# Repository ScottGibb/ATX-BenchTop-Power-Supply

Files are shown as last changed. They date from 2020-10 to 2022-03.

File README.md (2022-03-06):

# ATX-BenchTop-Power-Supply
Circuit diagram and Layout files for an ATX Bench Top open-source Power Supply

The circuit was created in Eagle using both through-hole and surface-mount components. The power supply board is developed such that it can use an old PC ATX power supply.
CAD design was done using Fusion 360 and will be available on thingiverse:

Thingiverse Link:
TBC

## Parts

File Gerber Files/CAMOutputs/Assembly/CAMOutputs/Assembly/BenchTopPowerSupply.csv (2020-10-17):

C7  3.29  5.94 270 0.1uF C1206
C9 28.94 84.82 180 0.1uF C1206
C10 37.96  5.52 270 0.1uF C1206
C11 118.75 62.00 180 0.1uF C1206
C12 133.73 77.01  90 01.uF C1206
C20 120.04 57.40 180 100nF C1206
C21 69.27 39.07   0 100nF C1206
C22 69.27 41.26   0 1uF C1206
C24 19.28 43.03 180 100nF C1206
C25 16.85 45.66 180 1uF C1206
C28 86.91 44.59 180 100nF C1206
C29 87.07 42.27 180 1uF C1206
C30 34.63 42.66   0 1uF C1206
C31 34.66 40.42   0 100nF C1206
C32 51.54 46.62 180 100nF C1206
C33 51.57 43.88 180 1uF C1206
C34 23.19 62.81  90 100nF C1206
C36 146.20 84.07   0 100uF C1206
C38 135.04 64.58   0 100uF C1206
R2 52.13  7.61  90 470 R1206
R3 20.00  6.76  90 470 R1206
R5  4.53 46.19  90 300K R1206
R6 151.13 13.97   0 220 R1206
R7 135.89 13.97   0 220 R1206
R8 119.38 13.97   0 470 R1206
R9 51.08 33.63   0 10k R1206
R10 64.77 74.93  90 220 R1206
R11 46.56 90.30 180 220 R1206
R12 17.67 33.15   0 10k R1206
R13 87.17 32.41   0 10k R1206
R14  6.27 42.48   0 100K R1206
R15  7.67 10.74 270 0.1R RESC6335X60N
R18 130.10 83.19 180 0.005 RESC6335X60N
R19 29.21 76.20   0 0.005 RESC6335X60N
R20 114.30 68.58 180 0.005 RESC6335X60N
R21 37.05 33.03  90 300K R1206
R22 37.07 26.10  90 100K R1206
R26 109.58 62.92 180 30K R1206
R27 125.32 78.16   0 30K R1206
R28 34.06 82.91   0 30K R1206
R30  1.92 15.05 270 10k R1206
R35 29.92 63.28  90 10k R1206
R36 29.91 58.05  90 10k R1206
U1  3.63 11.00 270  SOT95P240X110-5N
U4 29.26 81.28   0  SOT95P240X110-5N
U5 130.05 77.47 180  SOT95P240X110-5N
U6 114.05 64.26 180  SOT95P240X110-5N

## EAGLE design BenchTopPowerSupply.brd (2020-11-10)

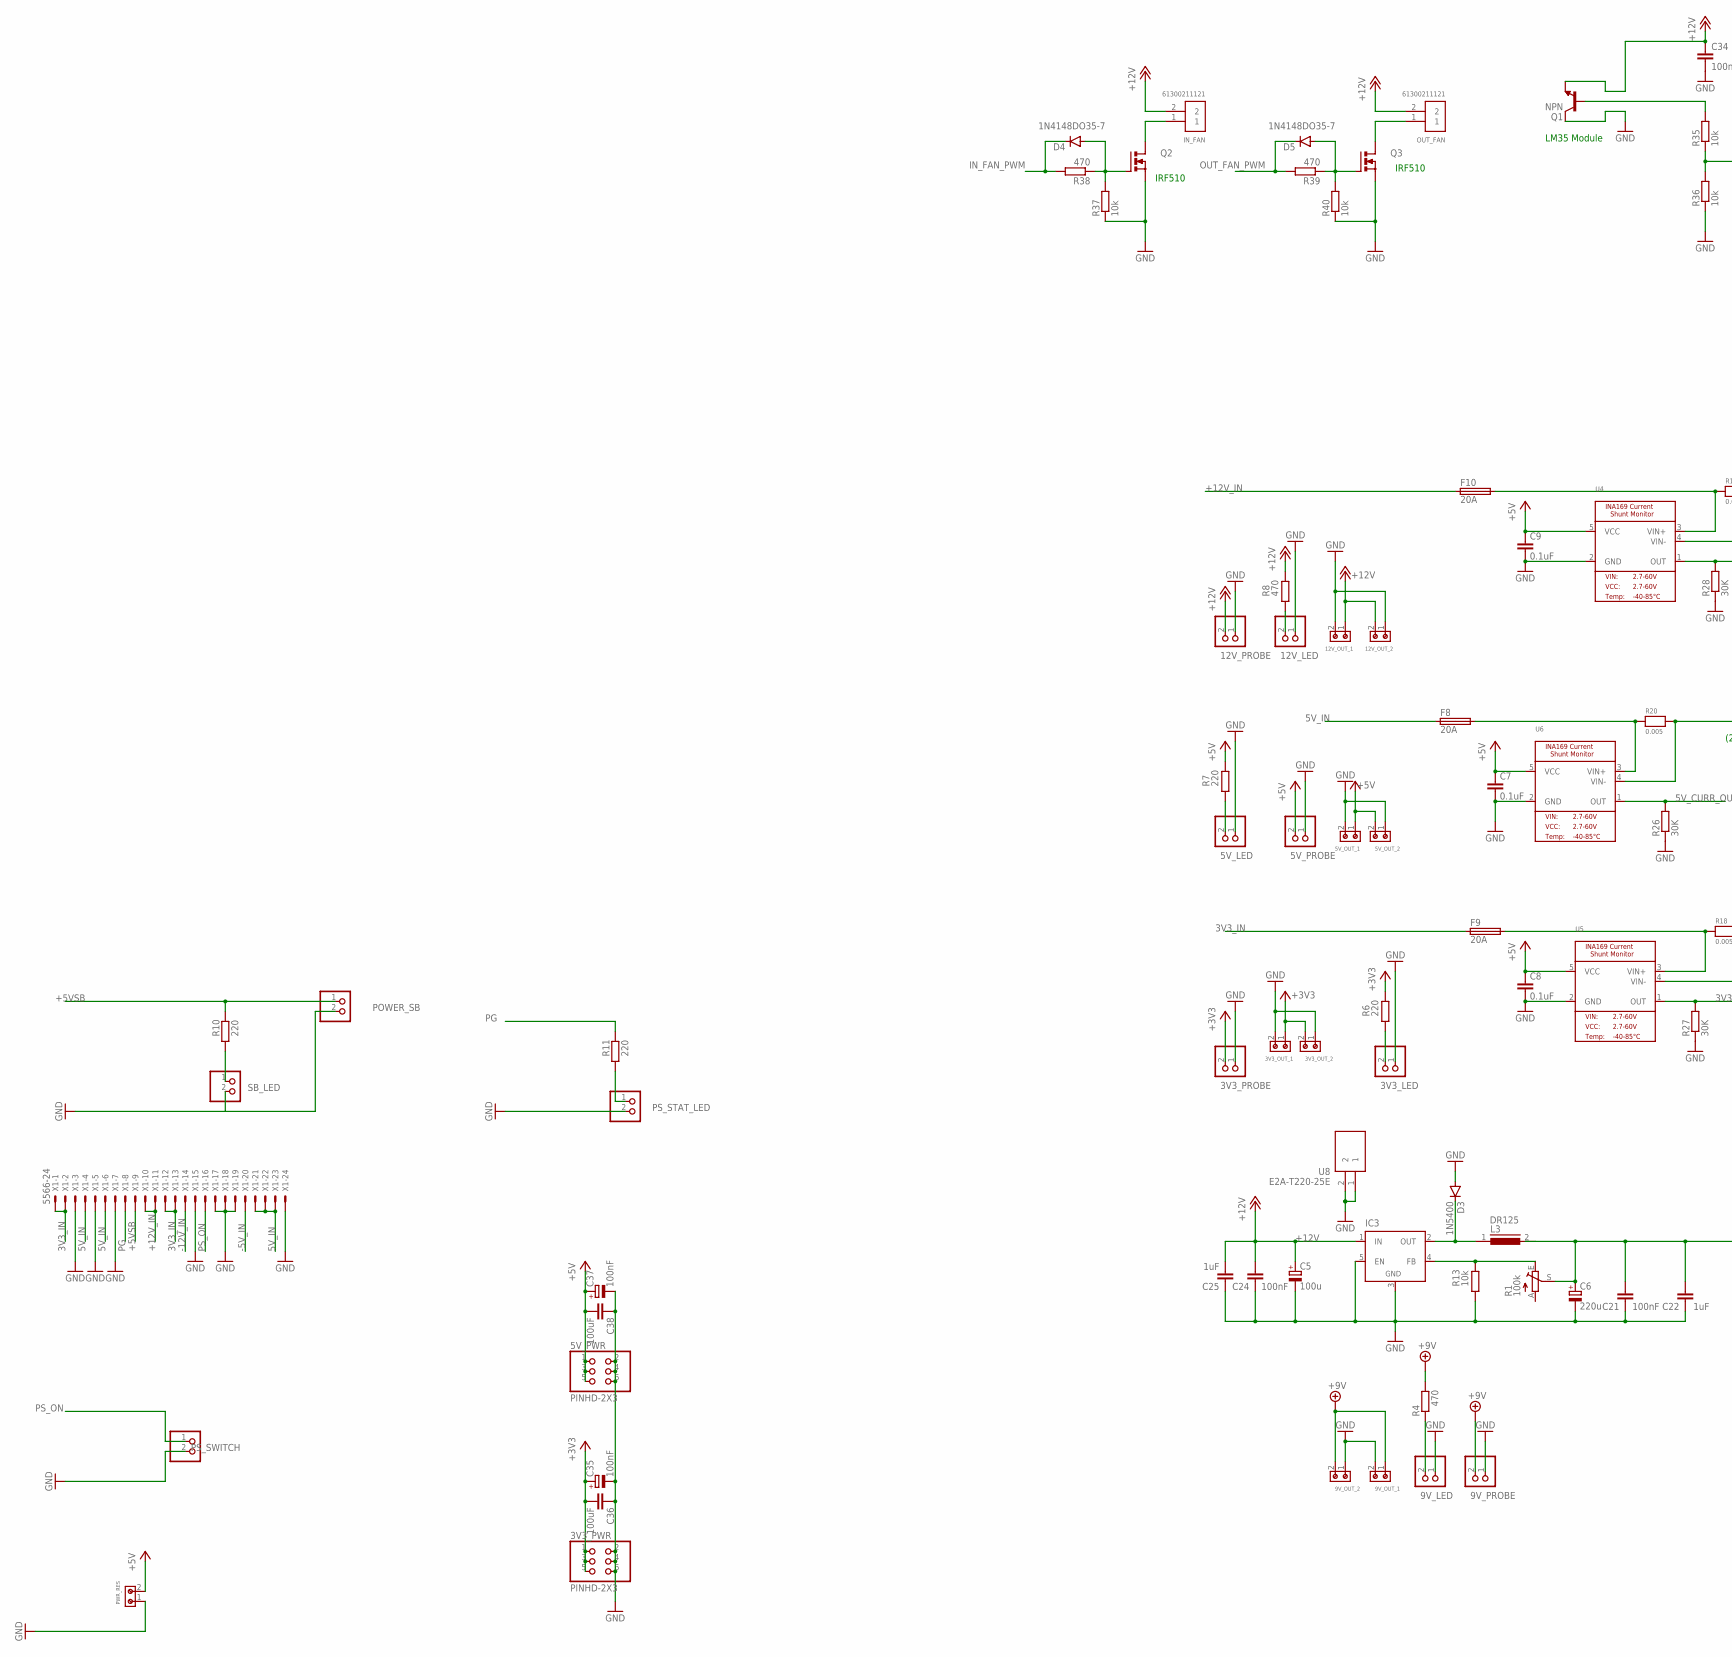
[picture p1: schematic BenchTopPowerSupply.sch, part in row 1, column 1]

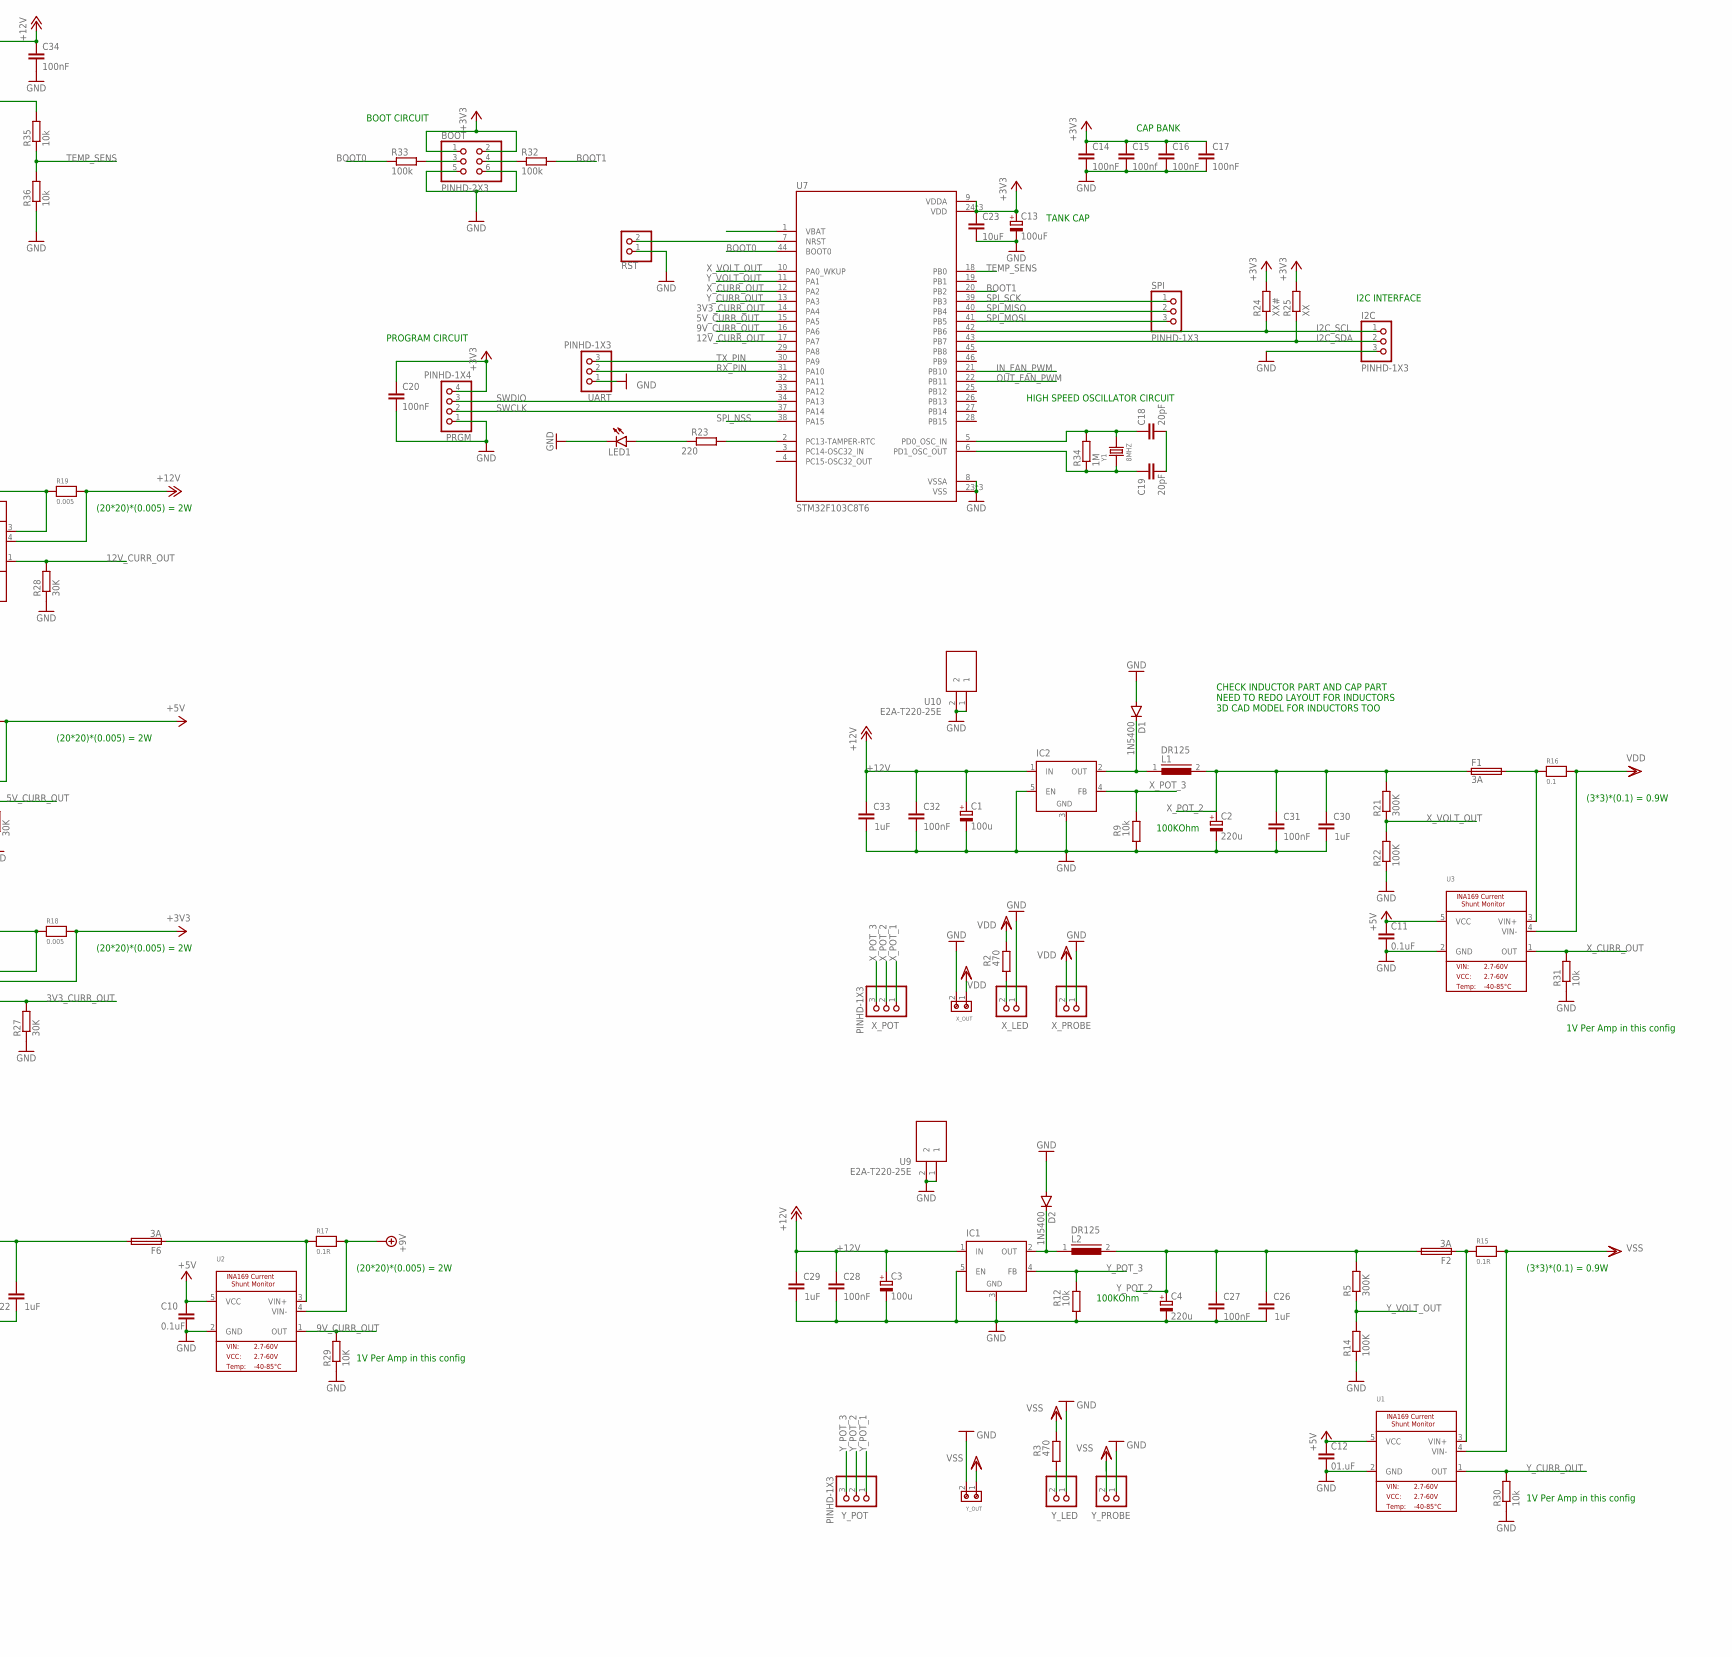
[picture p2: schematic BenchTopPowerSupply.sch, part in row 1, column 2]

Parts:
3V3_LED, 3V3_PROBE, 5V_LED, 5V_PROBE, 9V_LED, 9V_PROBE, 12V_LED, 12V_PROBE: PINHD-1X2; 1X02
3V3_OUT_1, 3V3_OUT_2, 5V_OUT_1, 5V_OUT_2, 9V_OUT_1, 9V_OUT_2, 12V_OUT_1, 12V_OUT_2: 691216510002S
3V3_PWR, 5V_PWR: PINHD-2X3; 2X03
BOOT: PINHD-2X3; 2X03
C1, C3, C5: 100u; E5-10,5
C2, C4, C6: 220u; E5-10,5
C7, C8, C9, C10, C11: 0.1uF; C1206
C12: 01.uF; C1206
C13: 100uF; E5-5
C14, C16, C17, C20, C21, C24, C27, C28, C31, C32, C34: 100nF; C1206
C15: 100nf; C1206
C18, C19: 20pF; C1206
C22, C25, C26, C29, C30, C33: 1uF; C1206
C23: 10uF; C1206
C35, C37: 100nF; E5-5
C36, C38: 100uF; C1206
D1, D2, D3: 1N5400; DO201-15
D4, D5: 1N4148DO35-7; DO35-7
F1, F2, F6: 3A; SHK20L
F8, F9, F10: 20A; SHK20L
I2C: PINHD-1X3; 1X03
IC1, IC2, IC3: LM2596TV; TO220-51
IN_FAN: 61300211121
L1, L2, L3: DR125
LED1: LED5MM
OUT_FAN: 61300211121
POWER_SB: PINHD-1X2; 1X02
PRGM: PINHD-1X4; 1X04
PS_STAT_LED: PINHD-1X2; 1X02
PS_SWITCH: PINHD-1X2; 1X02
PWR_RES: 691216510002S
Q1: NPN; TO92
Q2, Q3: IRF510; TO220BV
R1: 100k; S64W
R2, R3, R4, R8, R38, R39: 470; R1206
R5, R21: 300K; R1206
R6, R7, R10, R11, R23: 220; R1206
R9, R12, R13, R30, R31, R35, R36, R37, R40: 10k; R1206
R14, R22: 100K; R1206
R15, R17: 0.1R; RESC6335X60N
R16: 0.1; RESC6335X60N
R18, R19, R20: 0.005; RESC6335X60N
R24: XX#; R1206
R25: XX; R1206
R26, R27, R28: 30K; R1206
R29: 10K; R1206
R32, R33: 100k; R1206
R34: 1M; R1206
RST: PINHD-1X2; 1X02
SB_LED: PINHD-1X2; 1X02
SPI: PINHD-1X3; 1X03
U1, U2, U3, U4, U5, U6: MICROBUILDER_INA1693D_PACKAGE; SOT95P240X110-5N
U7: STM32F103C8T6; QFP50P900X900X160-48N
U8, U9, U10: E2A-T220-25E; E2AT22025E
UART: PINHD-1X3; 1X03
X1: 5566-24
X_LED: PINHD-1X2; 1X02
X_OUT: 691216510002S
X_POT: PINHD-1X3; 1X03
X_PROBE: PINHD-1X2; 1X02
Y1: 8MHZ; HC49US
Y_LED: PINHD-1X2; 1X02
Y_OUT: 691216510002S
Y_POT: PINHD-1X3; 1X03
Y_PROBE: PINHD-1X2; 1X02

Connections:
2B: F2.1A, R15.1, U1.3 (VIN+)
3V3_CURR_OUT: R27.2, U5.1 (OUT), U7.14 (PA4)
3V3_IN: F9.1A, X1.1, X1.2, X1.12, X1.13
5V_CURR_OUT: R26.2, U6.1 (OUT), U7.15 (PA5)
5V_IN: F8.1A, X1.4, X1.6, X1.21, X1.22, X1.23
9V_CURR_OUT: R29.2, U2.1 (OUT), U7.16 (PA6)
12V_CURR_OUT: R28.2, U4.1 (OUT), U7.17 (PA7)
+3V3: 3V3_OUT_1.1, 3V3_OUT_2.2, 3V3_PROBE.2, 3V3_PWR.1, 3V3_PWR.3, 3V3_PWR.5, BOOT.1, BOOT.2, C13.+, C14.1, C15.1, C16.1, C17.1, C20.1, C23.1, C35.+, C36.2, PRGM.4, R6.2, R18.2, R24.2, R25.2, U5.4 (VIN-), U7.9 (VDDA), U7.24 (VDD), U7.36 (VDD), U7.48 (VDD)
+5V: 5V_OUT_1.1, 5V_OUT_2.2, 5V_PROBE.2, 5V_PWR.1, 5V_PWR.3, 5V_PWR.5, C7.1, C8.1, C9.1, C10.1, C11.1, C12.1, C37.+, C38.2, PWR_RES.2, R7.2, R20.2, U1.5 (VCC), U2.5 (VCC), U3.5 (VCC), U4.5 (VCC), U5.5 (VCC), U6.4 (VIN-), U6.5 (VCC)
+5VSB: POWER_SB.1, R10.2, X1.9
+9V: 9V_OUT_1.1, 9V_OUT_2.2, 9V_PROBE.2, R4.2, R17.2, U2.4 (VIN-)
+12V: 12V_OUT_1.1, 12V_OUT_2.2, 12V_PROBE.2, C1.+, C3.+, C5.+, C24.2, C25.2, C28.2, C29.2, C32.2, C33.2, C34.1, IC1.1 (IN), IC2.1 (IN), IC3.1 (IN), IN_FAN.2, OUT_FAN.2, Q1.1 (E), R8.2, R19.2, U4.4 (VIN-)
+12V_IN: F10.1A, X1.10, X1.11
-5V_IN: X1.20
-12V_IN: X1.14
BOOT0: R33.1, U7.44 (BOOT0)
BOOT1: R32.2, U7.20 (PB2)
GND: 3V3_LED.1, 3V3_OUT_1.2, 3V3_OUT_2.1, 3V3_PROBE.1, 3V3_PWR.2, 3V3_PWR.4, 3V3_PWR.6, 5V_LED.1, 5V_OUT_1.2, 5V_OUT_2.1, 5V_PROBE.1, 5V_PWR.2, 5V_PWR.4, 5V_PWR.6, 9V_LED.1, 9V_OUT_1.2, 9V_OUT_2.1, 9V_PROBE.1, 12V_LED.1, 12V_OUT_1.2, 12V_OUT_2.1, 12V_PROBE.1, BOOT.5, BOOT.6, C1.-, C2.-, C3.-, C4.-, C5.-, C6.-, C7.2, C8.2, C9.2, C10.2, C11.2, C12.2, C13.-, C14.2, C15.2, C16.2, C17.2, C20.2, C21.1, C22.1, C23.2, C24.1, C25.1, C26.1, C27.1, C28.1, C29.1, C30.1, C31.1, C32.1, C33.1, C34.2, C35.-, C36.1, C37.-, C38.1, D1.A, D2.A, D3.A, I2C.3, IC1.3 (GND), IC1.5 (EN), IC2.3 (GND), IC2.5 (EN), IC3.3 (GND), IC3.5 (EN), LED1.K (C), POWER_SB.2, PRGM.1, PS_STAT_LED.2, PS_SWITCH.2, PWR_RES.1, Q1.3 (C), Q2.S, Q3.S, R9.1, R12.1, R13.1, R14.1, R22.1, R26.1, R27.1, R28.1, R29.1, R30.1, R31.1, R36.1, R37.1, R40.1, RST.1, SB_LED.2, U1.2 (GND), U2.2 (GND), U3.2 (GND), U4.2 (GND), U5.2 (GND), U6.2 (GND), U7.8 (VSSA), U7.23 (VSS), U7.35 (VSS), U7.47 (VSS), U8.1, U8.2, U9.1, U9.2, U10.1, U10.2, UART.1, X1.3, X1.5, X1.7, X1.15, X1.17, X1.18, X1.19, X1.24, X_LED.1, X_OUT.2, X_PROBE.1, Y_LED.1, Y_OUT.2, Y_PROBE.1
I2C_SCL: I2C.1, R24.1, U7.42 (PB6)
I2C_SDA: I2C.2, R25.1, U7.43 (PB7)
IN_FAN_PWM: D4.C, R38.2, U7.21 (PB10)
unnamed: D3.C, IC3.2 (OUT), L3.1
unnamed: IC3.4 (FB), R1.E, R13.2
unnamed: C18.1, R34.2, U7.5 (PD0_OSC_IN), Y1.2
unnamed: D1.C, IC2.2 (OUT), L1.1
unnamed: C19.1, R34.1, U7.6 (PD1_OSC_OUT), Y1.1
unnamed: F8.2A, R20.1, U6.3 (VIN+)
unnamed: R3.1, Y_LED.2
unnamed: R2.1, X_LED.2
unnamed: 9V_LED.2, R4.1
unnamed: C18.2, C19.2
unnamed: 3V3_LED.2, R6.1
unnamed: 5V_LED.2, R7.1
unnamed: 12V_LED.2, R8.1
unnamed: R10.1, SB_LED.1
unnamed: PS_STAT_LED.1, R11.1
unnamed: BOOT.4, R32.1
unnamed: C6.+, C21.2, C22.2, F6.2A, L3.2, R1.S
unnamed: D2.C, IC1.2 (OUT), L2.1
unnamed: F9.2A, R18.1, U5.3 (VIN+)
unnamed: F1.2A, R16.1, U3.3 (VIN+)
unnamed: F10.2A, R19.1, U4.3 (VIN+)
unnamed: F6.1A, R17.1, U2.3 (VIN+)
unnamed: RST.2, U7.7 (NRST)
unnamed: Q1.2 (B), R35.2
unnamed: R23.2, U7.2 (PC13-TAMPER-RTC)
unnamed: LED1.A, R23.1
unnamed: BOOT.3, R33.2
unnamed: D4.A, Q2.G, R37.2, R38.1
unnamed: IN_FAN.1, Q2.D
unnamed: D5.A, Q3.G, R39.1, R40.2
unnamed: OUT_FAN.1, Q3.D
OUT_FAN_PWM: D5.C, R39.2, U7.22 (PB11)
PG: R11.2, X1.8
PS_ON: PS_SWITCH.1, X1.16
RX_PIN: U7.31 (PA10), UART.2
SPI_MISO: SPI.2, U7.40 (PB4)
SPI_MOSI: SPI.3, U7.41 (PB5)
SPI_NSS: U7.38 (PA15)
SPI_SCK: SPI.1, U7.39 (PB3)
SWCLK: PRGM.2, U7.37 (PA14)
SWDIO: PRGM.3, U7.34 (PA13)
TEMP_SENS: R35.1, R36.2, U7.18 (PB0)
TX_PIN: U7.30 (PA9), UART.3
VDD: R2.2, R16.2, U3.4 (VIN-), X_OUT.1, X_PROBE.2
VSS: R3.2, R15.2, U1.4 (VIN-), Y_OUT.1, Y_PROBE.2
X_CURR_OUT: R31.2, U3.1 (OUT), U7.12 (PA2)
X_POT_1: X_POT.1
X_POT_2: C2.+, C30.2, C31.2, F1.1A, L1.2, R21.2, X_POT.2
X_POT_3: IC2.4 (FB), R9.2, X_POT.3
X_VOLT_OUT: R21.1, R22.2, U7.10 (PA0_WKUP)
Y_CURR_OUT: R30.2, U1.1 (OUT), U7.13 (PA3)
Y_POT_1: Y_POT.1
Y_POT_2: C4.+, C26.2, C27.2, F2.2A, L2.2, R5.2, Y_POT.2
Y_POT_3: IC1.4 (FB), R12.2, Y_POT.3
Y_VOLT_OUT: R5.1, R14.2, U7.11 (PA1)

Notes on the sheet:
CHECK INDUCTOR PART AND CAP PART NEED TO REDO LAYOUT FOR INDUCTORS 3D CAD MODEL FOR INDUCTORS TOO
BOOT CIRCUIT
PROGRAM CIRCUIT
HIGH SPEED OSCILLATOR CIRCUIT
I2C INTERFACE
CAP BANK
TANK CAP
1V Per Amp in this config
(20*20)*(0.005) = 2W
(3*3)*(0.1) = 0.9W
LM35 Module
IRF510
100KOhm

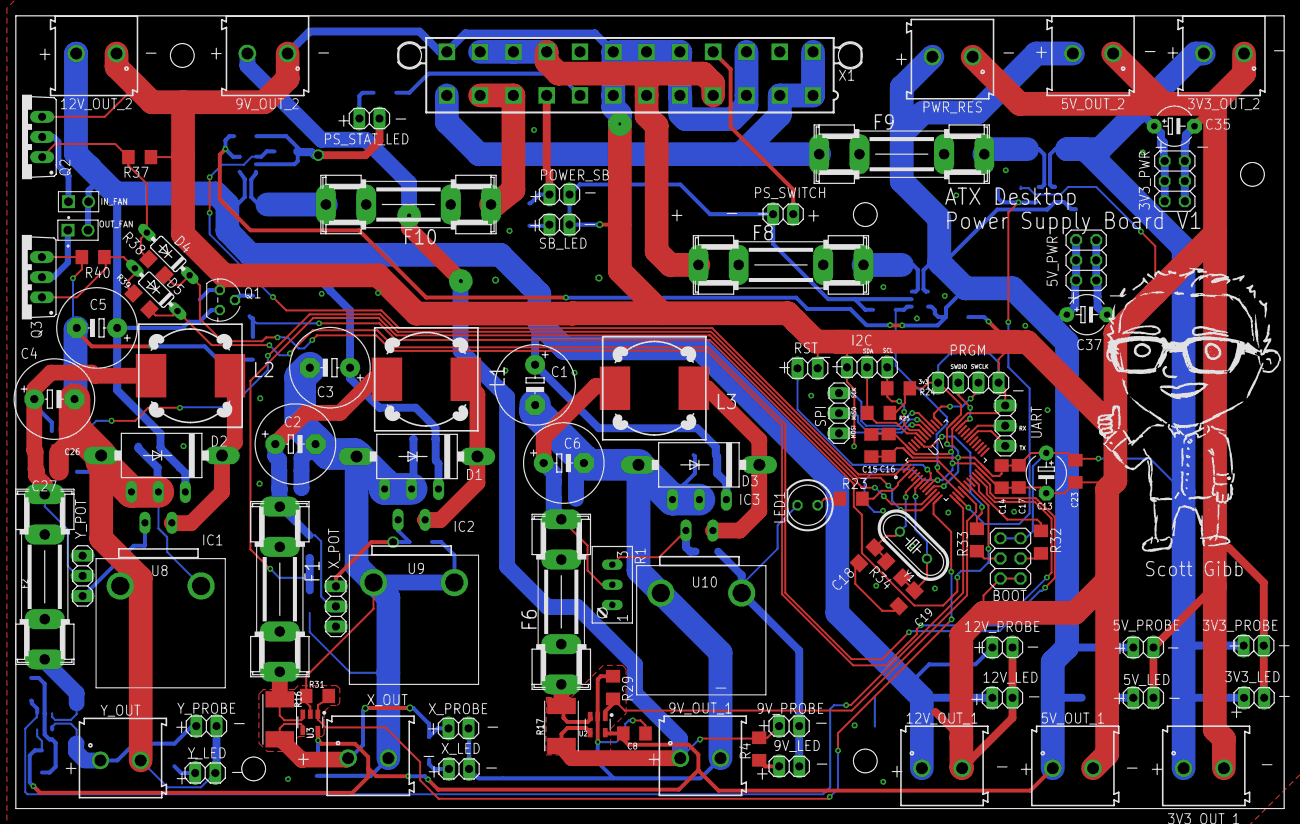
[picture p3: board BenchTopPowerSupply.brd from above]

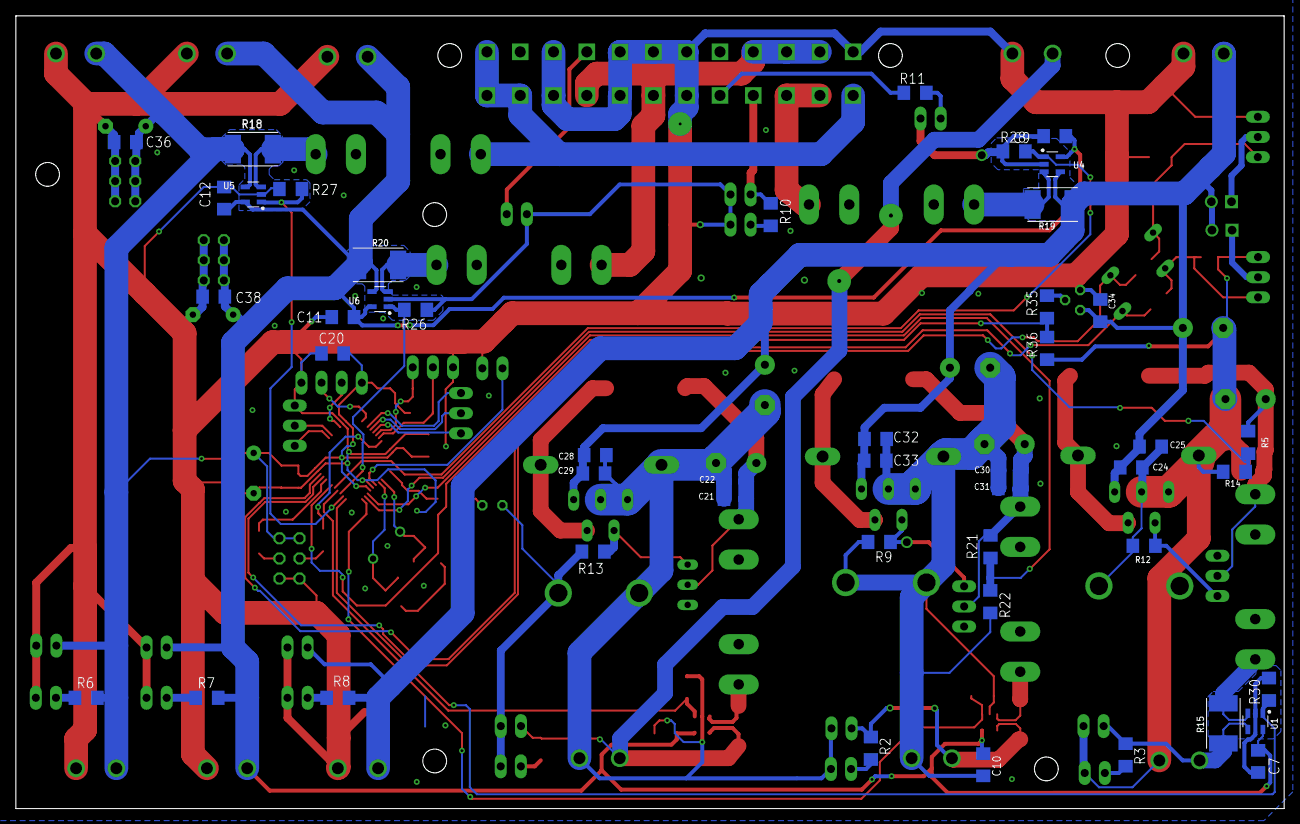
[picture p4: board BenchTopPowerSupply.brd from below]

Board: 2 copper layers, 160.0 x 100.0 mm, 150 parts (47 on the bottom side), 71 nets.

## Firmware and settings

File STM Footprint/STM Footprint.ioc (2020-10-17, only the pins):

Mcu.UserName=STM32F103C8Tx
PA6.GPIO_Label=CURR_9V
PB0.GPIO_Label=TEMP_SENS
PB11.Signal=S_TIM2_CH4
PD1-OSC_OUT.Signal=RCC_OSC_OUT
PB6.Signal=I2C1_SCL
PB7.Signal=I2C1_SDA
PA6.Signal=ADCx_IN6
PA2.GPIO_Label=CURR_X
PA10.Signal=USART1_RX
PA15.Signal=SPI1_NSS
PA4.GPIO_Label=CURR_3V3
PB4.Signal=SPI1_MISO
PA3.Signal=ADCx_IN3
PB11.GPIO_Label=OUT_FAN_PWM
PC13-TAMPER-RTC.Signal=GPIO_Output
PD0-OSC_IN.Signal=RCC_OSC_IN
PA0-WKUP.GPIO_Label=VOLT_X
PA0-WKUP.Signal=ADCx_IN0
PA13.Signal=SYS_JTMS-SWDIO
PB10.GPIO_Label=IN_FAN_PWM
PA9.Signal=USART1_TX
PA1.Signal=ADCx_IN1
PB10.Signal=S_TIM2_CH3
PA5.Signal=ADCx_IN5
PA1.GPIO_Label=VOLT_Y
PA2.Signal=ADCx_IN2
PB3.Signal=SPI1_SCK
PA4.Signal=ADCx_IN4
PB5.Signal=SPI1_MOSI
PA7.GPIO_Label=CURR_12V
PA5.GPIO_Label=CURR_5V
PA14.Signal=SYS_JTCK-SWCLK
PB0.Signal=ADCx_IN8
PA3.GPIO_Label=CURR_Y
PA7.Signal=ADCx_IN7

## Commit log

2020-09-27 Adding Schematics, layout and CubeMX Files
    [BenchTopPowerSupply.brd, BenchTopPowerSupply.sch]
2020-10-04 Fixing schematic issues
    [BenchTopPowerSupply.brd, BenchTopPowerSupply.sch]
2020-10-17 Adding mounting holes to the design and experimenting with JLCPCB SMT assembly
    [BenchTopPowerSupply.brd, BenchTopPowerSupply.csv, BenchTopPowerSupply.sch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]
2020-11-10 Changing to surface mount inductors, reduce noise on board, hopefully. Will need to redo layout however and figure out how to solder them
    [BenchTopPowerSupply.brd, BenchTopPowerSupply.sch]
2020-11-10 updating layout silkskin, one final check then sending away for manufacture
    [BenchTopPowerSupply.brd, BenchTopPowerSupply.sch]

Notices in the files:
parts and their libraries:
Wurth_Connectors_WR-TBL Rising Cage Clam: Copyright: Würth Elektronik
